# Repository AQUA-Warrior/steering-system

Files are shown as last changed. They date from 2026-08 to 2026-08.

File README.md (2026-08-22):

## Custom Steering + Throttle/Brake System & Devboard

> *If You Want Total Control, You Have To Make It Yourself*

### Project Overview:
A custom, embedded hardware project to make my very own sim racing steering wheel and pedal systems. The project is powered by the STM32F732RET6 chip, using hall effect sensors for measuring inputs of the steering, throttle, and braking.

### Purpose Of The Project:
I started making this project knowing basically nothing about communication protocols or chip architectures. Instead of buying adapters that are already made for you. I wanted to make the entire system myself to learn and expand my knowledge, and create my very own sim racing setup. By designing this myself, I learned the strengths and weaknesses of communication protocols and which ones were best for which purpose. I wired up all the unused GPIO pins on the chip to connectors so that I would not just be locked down to the steering project, but instead, I can use it as a general purpose devboard for any future embedded hardware project I want to do.

### The Repository Contains:
- KiCad schematics and PCB's for the devboard and AS5048A adapter board.
- STM32CubeMX pinouts for the devboard.
- This repository will in the future contain the firmware/software.

### Main Board Hardware:
- **Chip:** STM32F732RET6 (64-pin)
- **Power:** 5V VBUS from the USB-C, regulated to 3V3 using an AP2112k

### Main Board Design:
- 2 Layer PCB
- Minimum component size of 0603 used
- Two mounting holes (One on top right, One on bottom left)
- GND Zone on front copper
- 3V3 Zone on back copper

### AS5048A Adapter Board Design:
- 1 Layer PCB
- Minimum component size of 0603 used
- Two mounting holes (One on top right, One on bottom left)
- GND Zone on front copper

## Visuals
### Main Board Schematic:
main_schematic

### Main Board PCB:
main_PCB

### Main Board 3D View:
main_3D

### AS5048A Adapter Board Schematic:
AS5048A_schematic

### AS5048A Adapter Board PCB:
AS5048A_PCB

### AS5048A Adapter Board 3D View:
AS5048A_3D

## Bill Of Materials:

### Main Board:

| # | Reference | Qty | Value | Manufacturer | Manufacturer Part # | Footprint | Description | Price (1 Component) | Link |
|---:|---|---:|---|---|---|---|---|---:|---|
| 1 | F1 | 1 | Polyfuse | YAGEO | SMD0603B050TF | `Fuse:Fuse_0603_1608Metric_Pad1.05x0.95mm_HandSolder` | Resettable fuse, polymeric positive temperature coefficient | $0.36 | [DigiKey](https://www.digikey.ca/en/products/detail/yageo/SMD0603B050TF/15212923) |
| 2 | SW2 | 1 | SW_SPDT | Wurth Elektronik | 4.5E+11 | `450406020024:450406020024` | 9.0 × 3.5 mm, SPDT, ON-ON, Pitch 2.5 mm, Vertical type, SMT, T&R | $2.51 | [DigiKey](https://www.digikey.ca/en/products/detail/w%C3%BCrth-elektronik/450406020024/26249501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) |
| 3 | D1 | 1 | RED | Wurth Elektronik | 150060RS75000 | `LED_SMD:LED_0603_1608Metric_Pad1.05x0.95mm_HandSolder` | Light emitting diode | $0.15 | [DigiKey](https://www.digikey.ca/en/products/detail/w%C3%BCrth-elektronik/150060RS75000/4489901) |
| 4 | U2 | 1 | USBLC6-2SC6 | Shenzhen Slkormicro Semicon Co., Ltd. | USBLC6-2SC6 | `Package_TO_SOT_SMD:SOT-23-6` | Very low capacitance ESD protection diode, 2 data-line, SOT-23-6 | $0.18 | [DigiKey](https://www.digikey.ca/en/products/detail/shenzhen-slkormicro-semicon-co-ltd/USBLC6-2SC6/28143029) |
| 5 | U1 | 1 | STM32F732RET6 | STMicroelectronics | STM32F732RET6 | `Package_QFP:LQFP-64_10x10mm_P0.5mm` | STMicroelectronics Arm Cortex-M7 MCU, 512KB flash, 256KB RAM, 216 MHz, 1.7–3.6V, 50 GPIO, LQFP64 | $15.43 | [DigiKey](https://www.digikey.ca/en/products/detail/stmicroelectronics/STM32F732RET6/6621779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) |
| 6 | R4 | 1 | 100 | Panasonic Industry | ERJ-PA3F1000V | `Resistor_SMD:R_0603_1608Metric_Pad0.98x0.95mm_HandSolder` | Resistor | $0.24 | [DigiKey](https://www.digikey.ca/en/products/detail/panasonic-industry/ERJ-PA3F1000V/5035847) |
| 7 | R2, R3 | 2 | 5.1k | Panasonic Industry | ERJ-3GEYJ512V | `Resistor_SMD:R_0603_1608Metric_Pad0.98x0.95mm_HandSolder` | Resistor | $0.10 | [DigiKey](https://www.digikey.ca/en/products/detail/panasonic-industry/ERJ-3GEYJ512V/135918) |
| 8 | R1 | 1 | 10k | Panasonic Industry | ERJ-3EKF1002V | `Resistor_SMD:R_0603_1608Metric_Pad0.98x0.95mm_HandSolder` | Resistor | $0.10 | [DigiKey](https://www.digikey.ca/en/products/detail/panasonic-industry/ERJ-3EKF1002V/196066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) |
| 9 | FB1 | 1 | 120R | Murata Electronics | BLM18AG121SN1D | `Inductor_SMD:L_0603_1608Metric_Pad1.05x0.95mm_HandSolder` | Ferrite bead | $0.16 | [DigiKey](https://www.digikey.ca/en/products/detail/murata-electronics/BLM18AG121SN1D/584222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) |
| 10 | C16 | 1 | 2.2uF | Murata Electronics | GRT188R61H225KE13D | `Capacitor_SMD:C_0603_1608Metric_Pad1.08x0.95mm_HandSolder` | Unpolarized capacitor | $0.20 | [DigiKey](https://www.digikey.ca/en/products/detail/murata-electronics/GRT188R61H225KE13D/5416754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) |
| 11 | C11, C12 | 2 | 10pF | Murata Electronics | GCM1555C1H100JA16D | `Capacitor_SMD:C_0603_1608Metric_Pad1.08x0.95mm_HandSolder` | Unpolarized capacitor | $0.11 | [DigiKey](https://www.digikey.ca/en/products/detail/murata-electronics/GCM1555C1H100JA16D/4903546) |
| 12 | C8, C9, C14, C15 | 4 | 1uF | Murata Electronics | GRT188C8YA105KE13D | `Capacitor_SMD:C_0603_1608Metric_Pad1.08x0.95mm_HandSolder` | Unpolarized capacitor | $0.17 | [DigiKey](https://www.digikey.ca/en/products/detail/murata-electronics/GRT188C8YA105KE13D/5416719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) |
| 13 | C7 | 1 | 10nF | Murata Electronics | GCM188R72A103KA37D | `Capacitor_SMD:C_0603_1608Metric_Pad1.08x0.95mm_HandSolder` | Unpolarized capacitor | $0.15 | [DigiKey](https://www.digikey.ca/en/products/detail/murata-electronics/GCM188R72A103KA37D/1641655) |
| 14 | C6, C17 | 2 | 10uF | Murata Electronics | GCJ21BR71A106KE01L | `Capacitor_SMD:C_0805_2012Metric_Pad1.18x1.45mm_HandSolder` | Unpolarized capacitor | $0.74 | [DigiKey](https://www.digikey.ca/en/products/detail/murata-electronics/GCJ21BR71A106KE01L/4903511) |
| 15 | C1, C2, C3, C4, C5, C10 | 6 | 100nF | Murata Electronics | GCM188L81H104KA57D | `Capacitor_SMD:C_0603_1608Metric_Pad1.08x0.95mm_HandSolder` | Unpolarized capacitor | $0.14 | [DigiKey](https://www.digikey.ca/en/products/detail/murata-electronics/GCM188L81H104KA57D/2591908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) |
| 16 | D2 | 1 | D_TVS | KYOCERA AVX | GG060305100N2P | `Diode_SMD:D_0603_1608Metric_Pad1.05x0.95mm_HandSolder` | Bidirectional transient-voltage-suppression diode | $0.45 | [DigiKey](https://www.digikey.ca/en/products/detail/kyocera-avx/GG060305100N2P/14552130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) |
| 17 | Y1 | 1 | 16MHz | Jauch Quartz | Q 16,0-JXS32-8-10/10-WA-LF | `Crystal:Crystal_SMD_3225-4Pin_3.2x2.5mm_HandSoldering` | Four pin crystal, GND on pins 2 and 4 | $0.61 | [DigiKey](https://www.digikey.ca/en/products/detail/jauch-quartz/Q-16-0-JXS32-8-10-10-WA-LF/8108046) |
| 18 | J1 | 1 | USB_C_Receptacle_USB2.0_14P | GCT | USB4085-GF-A | `Connector_USB:USB_C_Receptacle_GCT_USB4085` | USB 2.0-only 14P Type-C Receptacle connector | $0.91 | [DigiKey](https://www.digikey.ca/en/products/detail/gct/USB4085-GF-A/9859662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) |
| 19 | U3 | 1 | AP2112K-3.3 | Diodes Incorporated | AP2112K-3.3TRG1 | `Package_TO_SOT_SMD:SOT-23-5` | 600mA low dropout linear regulator, with enable pin, 3.8–6V input voltage range, 3.3V fixed positive output, SOT-23-5 | $0.28 | [DigiKey](https://www.digikey.ca/en/products/detail/diodes-incorporated/AP2112K-3-3TRG1/4470746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) |
| 20 | SW1 | 1 | SW_Push | Alps Alpine | SKSGACE010 | `ul_SKSGACE010:SKSGACE010_ALPS` | Push button switch, generic, two pins | $0.45 | [DigiKey](https://www.digikey.ca/en/products/detail/alps-alpine/SKSGACE010/19529157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) |
| 21 | J8 | 1 | Conn_01x15_Socket | — | — | `Connector_PinHeader_2.54mm:PinHeader_1x15_P2.54mm_Vertical` | Generic connector, single row, 01x15, script generated | — | — |
| 22 | J7 | 1 | Conn_01x21_Socket | — | — | `Connector_PinHeader_2.54mm:PinHeader_1x21_P2.54mm_Vertical` | Generic connector, single row, 01x21, script generated | — | — |
| 23 | J6 | 1 | Conn_01x02_Socket USART2 | — | — | `Connector_PinHeader_2.54mm:PinHeader_1x02_P2.54mm_Vertical` | Generic connector, single row, 01x02, script generated | — | — |
| 24 | J4, J5 | 2 | Conn_01x03_Socket A1324LLHLT-T | — | — | `Connector_PinHeader_2.54mm:PinHeader_1x03_P2.54mm_Vertical` | Generic connector, single row, 01x03, script generated | — | — |
| 25 | J3 | 1 | Conn_01x06_Socket | — | — | `Connector_PinHeader_2.54mm:PinHeader_1x06_P2.54mm_Vertical` | Generic connector, single row, 01x06, script generated | — | — |
| 26 | J2 | 1 | Conn_01x04_Pin | — | — | `Connector_PinHeader_2.54mm:PinHeader_1x04_P2.54mm_Vertical` | Generic connector, single row, 01x04, script generated | — | — |

### AS5048 Adapter Board:

| # | Reference | Qty | Value | Manufacturer | Manufacturer Part # | Footprint | Description | Price (1 Component) | Link |
|---:|---|---:|---|---|---|---|---|---:|---|
| 1 | C1 | 1 | 100nF | Murata Electronics | GCM188L81H104KA57D | `Capacitor_SMD:C_0603_1608Metric_Pad1.08x0.95mm_HandSolder` | Unpolarized capacitor | $0.14 | [DigiKey](https://www.digikey.ca/en/products/detail/murata-electronics/GCM188L81H104KA57D/2591908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) |
| 2 | C2 | 1 | 10uF | Murata Electronics | GCJ21BR71A106KE01L | `Capacitor_SMD:C_0805_2012Metric_Pad1.18x1.45mm_HandSolder` | Unpolarized capacitor | $0.50 | [DigiKey](https://www.digikey.ca/en/products/detail/murata-electronics/GCJ21BR71A106KE01L/4903511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) |
| 3 | J1 | 1 | Conn_01x07_Socket | — | — | `Connector_PinHeader_2.54mm:PinHeader_1x07_P2.54mm_Vertical` | Generic connector, single row, 01x07, script generated | — | — |
| 4 | U1 | 1 | AS5048A | ams OSRAM AG | AS5048A-HTSP-500 | `Package_SO:TSSOP-14_4.4x5mm_P0.65mm` | Magnetic position sensor, 14-bit, PWM output, SPI Interface, TSSOP-14 | $8.80 | [DigiKey](https://www.digikey.ca/en/products/detail/ams-osram-ag/AS5048A-HTSP-500/3188615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) |

### Linear Sensor:

| # | Reference | Qty | Value | Manufacturer | Manufacturer Part # | Footprint | Description | Price (1 Component) | Link |
|---:|---|---:|---|---|---|---|---|---:|---|
| 1 | — | 1 | — | Texas Instruments | DRV5055A1QLPG | — | SEN HALL EFFECT ANLG VOLT TO92-3 | $0.77 | [Digikey](https://www.digikey.ca/en/products/detail/texas-instruments/DRV5055A1QLPG) |

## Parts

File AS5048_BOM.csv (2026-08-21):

# | Reference | Qty | Value | MANUFACTURER | Manufacturer Part # | Footprint | Description | Price (1 Component) | Link
1 | C1 | 1 | 100nF | Murata Electronics | GCM188L81H104KA57D | Capacitor_SMD:C_0603_1608Metric_Pad1.08x0.95mm_HandSolder | Unpolarized capacitor | $0.14 | https://www.digikey.com/en/products/detail/murata-electronics/GCM188L81H104KA57D/2591908
2 | C2 | 1 | 10uF | Murata Electronics | GCJ21BR71A106KE01L | Capacitor_SMD:C_0805_2012Metric_Pad1.18x1.45mm_HandSolder | Unpolarized capacitor | $0.5 | https://www.digikey.com/en/products/detail/murata-electronics/GCJ21BR71A106KE01L/4903511
3 | J1 | 1 | Conn_01x07_Socket |  |  | Connector_PinHeader_2.54mm:PinHeader_1x07_P2.54mm_Vertical | Generic connector, single row, 01x07, script generated
4 | U1 | 1 | AS5048A | ams OSRAM AG | AS5048A-HTSP-500 | Package_SO:TSSOP-14_4.4x5mm_P0.65mm | Magnetic position sensor, 14-bit, PWM output, SPI Interface, TSSOP-14 | $8.8 | https://www.digikey.com/en/products/detail/ams-osram-ag/AS5048A-HTSP-500/3188615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

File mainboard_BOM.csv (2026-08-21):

# | Reference | Qty | Value | MANUFACTURER | Manufacturer Part # | Footprint | Description | Price (1 Component) | Link
1 | F1 | 1 | Polyfuse | YAGEO | SMD0603B050TF | Fuse:Fuse_0603_1608Metric_Pad1.05x0.95mm_HandSolder | Resettable fuse, polymeric positive temperature coefficient | $0.36 | https://www.digikey.ca/en/products/detail/yageo/SMD0603B050TF/15212923
2 | SW2 | 1 | SW_SPDT | Wurth Elektronik | 450406020024 | 450406020024:450406020024 | 9.0*3.5 mm, SPDT, ON-ON, Pitch 2.5mm, Vertical type, SMT, T&R | $2.51 | https://www.digikey.com/en/products/detail/w%C3%BCrth-elektronik/450406020024/26249501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
3 | D1 | 1 | RED | Wurth Elektronik | 150060RS75000 | LED_SMD:LED_0603_1608Metric_Pad1.05x0.95mm_HandSolder | Light emitting diode | $0.15 | https://www.digikey.com/en/products/detail/w%C3%BCrth-elektronik/150060RS75000/4489901
4 | U1 | 1 | STM32F732RET6 | STMicroelectronics | STM32F732RET6 | Package_QFP:LQFP-64_10x10mm_P0.5mm | STMicroelectronics Arm Cortex-M7 MCU, 512KB flash, 256KB RAM, 216 MHz, 1.7-3.6V, 50 GPIO, LQFP64 | $15.43 | https://www.digikey.com/en/products/detail/stmicroelectronics/STM32F732RET6/6621779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
5 | U2 | 1 | USBLC6-2SC6 | Shenzhen Slkormicro Semicon Co., Ltd. | USBLC6-2SC6 | Package_TO_SOT_SMD:SOT-23-6 | Very low capacitance ESD protection diode, 2 data-line, SOT-23-6 | $0.18 | https://www.digikey.com/en/products/detail/shenzhen-slkormicro-semicon-co-ltd/USBLC6-2SC6/28143029
6 | R4 | 1 | 100 | Panasonic Industry | ERJ-PA3F1000V | Resistor_SMD:R_0603_1608Metric_Pad0.98x0.95mm_HandSolder | Resistor | $0.24 | https://www.digikey.ca/en/products/detail/panasonic-industry/ERJ-PA3F1000V/5035847
7 | R2,R3 | 2 | 5.1k | Panasonic Industry | ERJ-3EKF5101V | Resistor_SMD:R_0603_1608Metric_Pad0.98x0.95mm_HandSolder | Resistor | $0.15 | https://www.digikey.com/en/products/detail/panasonic-industry/ERJ-PA3F1000V/5035847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
8 | R1 | 1 | 10k | Panasonic Industry | ERJ-3EKF1002V | Resistor_SMD:R_0603_1608Metric_Pad0.98x0.95mm_HandSolder | Resistor | $0.1 | https://www.digikey.com/en/products/detail/panasonic-industry/ERJ-3EKF1002V/196066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
9 | FB1 | 1 | 120R | Murata Electronics | BLM18AG121SN1D | Inductor_SMD:L_0603_1608Metric_Pad1.05x0.95mm_HandSolder | Ferrite bead | $0.16 | https://www.digikey.ca/en/products/detail/murata-electronics/BLM18AG121SN1D/584222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
10 | C16 | 1 | 2.2uF | Murata Electronics | GRT188R61H225KE13D | Capacitor_SMD:C_0603_1608Metric_Pad1.08x0.95mm_HandSolder | Unpolarized capacitor | $0.2 | https://www.digikey.com/en/products/detail/murata-electronics/GRT188R61H225KE13D/5416754
11 | C11,C12 | 2 | 10pF | Murata Electronics | GCM1555C1H100JA16D | Capacitor_SMD:C_0603_1608Metric_Pad1.08x0.95mm_HandSolder | Unpolarized capacitor | $0.11 | https://www.digikey.com/en/products/detail/murata-electronics/GCM1555C1H100JA16D/4903546
12 | C8,C9,C14,C15 | 4 | 1uF | Murata Electronics | GRT188C8YA105KE13D | Capacitor_SMD:C_0603_1608Metric_Pad1.08x0.95mm_HandSolder | Unpolarized capacitor | $0.17 | https://www.digikey.com/en/products/detail/murata-electronics/GRT188C8YA105KE13D/5416719
13 | C7 | 1 | 10nF | Murata Electronics | GCM188R72A103KA37D | Capacitor_SMD:C_0603_1608Metric_Pad1.08x0.95mm_HandSolder | Unpolarized capacitor | $0.15 | https://www.digikey.ca/en/products/detail/murata-electronics/GCM188R72A103KA37D/1641655
14 | C6,C17 | 2 | 10uF | Murata Electronics | GCJ21BR71A106KE01L | Capacitor_SMD:C_0805_2012Metric_Pad1.18x1.45mm_HandSolder | Unpolarized capacitor | $0.74 | https://www.digikey.ca/en/products/detail/murata-electronics/GCJ21BR71A106KE01L/4903511
15 | C1,C2,C3,C4,C5,C10 | 6 | 100nF | Murata Electronics | GCM188L81H104KA57D | Capacitor_SMD:C_0603_1608Metric_Pad1.08x0.95mm_HandSolder | Unpolarized capacitor | $0.14 | https://www.digikey.com/en/products/detail/murata-electronics/GCM188L81H104KA57D/2591908
16 | D2 | 1 | D_TVS | KYOCERA AVX | GG060305100N2P | Diode_SMD:D_0603_1608Metric_Pad1.05x0.95mm_HandSolder | Bidirectional transient-voltage-suppression diode | $0.45 | https://www.digikey.ca/en/products/detail/kyocera-avx/GG060305100N2P/14552130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
17 | Y1 | 1 | 16MHz | Jauch Quartz | Q 16,0-JXS32-8-10/10-WA-LF | Crystal:Crystal_SMD_3225-4Pin_3.2x2.5mm_HandSoldering | Four pin crystal, GND on pins 2 and 4 | $0.61 | https://www.digikey.com/en/products/detail/jauch-quartz/Q-16-0-JXS32-8-10-10-WA-LF/8108046
18 | J1 | 1 | USB_C_Receptacle_USB2.0_14P | GCT | USB4085-GF-A | Connector_USB:USB_C_Receptacle_GCT_USB4085 | USB 2.0-only 14P Type-C Receptacle connector | $0.91 | https://www.digikey.com/en/products/detail/gct/USB4085-GF-A/9859662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
19 | U3 | 1 | AP2112K-3.3 | Diodes Incorporated | AP2112K-3.3TRG1 | Package_TO_SOT_SMD:SOT-23-5 | 600mA low dropout linear regulator, with enable pin, 3.8V-6V input voltage range, 3.3V fixed positive output, SOT-23-5 | $0.28 | https://www.digikey.com/en/products/detail/diodes-incorporated/AP2112K-3-3TRG1/4470746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
20 | SW1 | 1 | SW_Push | Alps Alpine | SKSGACE010 | ul_SKSGACE010:SKSGACE010_ALPS | Push button switch, generic, two pins | $0.45 | https://www.digikey.com/en/products/detail/alps-alpine/SKSGACE010/19529157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
21 | J8 | 1 | Conn_01x15_Socket |  |  | Connector_PinHeader_2.54mm:PinHeader_1x15_P2.54mm_Vertical | Generic connector, single row, 01x15, script generated
22 | J7 | 1 | Conn_01x21_Socket |  |  | Connector_PinHeader_2.54mm:PinHeader_1x21_P2.54mm_Vertical | Generic connector, single row, 01x21, script generated
23 | J6 | 1 | Conn_01x02_Socket USART2 |  |  | Connector_PinHeader_2.54mm:PinHeader_1x02_P2.54mm_Vertical | Generic connector, single row, 01x02, script generated
24 | J4,J5 | 2 | Conn_01x03_Socket A1324LLHLT-T |  |  | Connector_PinHeader_2.54mm:PinHeader_1x03_P2.54mm_Vertical | Generic connector, single row, 01x03, script generated
25 | J3 | 1 | Conn_01x06_Socket |  |  | Connector_PinHeader_2.54mm:PinHeader_1x06_P2.54mm_Vertical | Generic connector, single row, 01x06, script generated
26 | J2 | 1 | Conn_01x04_Pin |  |  | Connector_PinHeader_2.54mm:PinHeader_1x04_P2.54mm_Vertical | Generic connector, single row, 01x04, script generated

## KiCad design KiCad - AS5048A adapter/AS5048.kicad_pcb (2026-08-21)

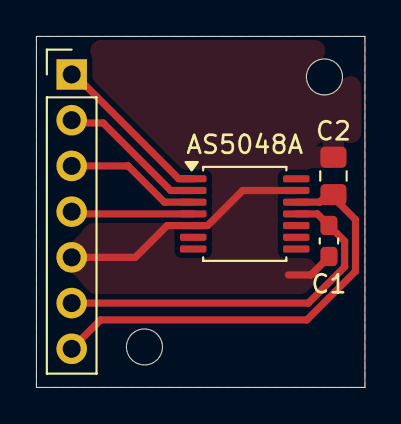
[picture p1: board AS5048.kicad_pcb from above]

Board: 2 copper layers, 18.2 x 19.5 mm, 4 parts (0 on the bottom side), 7 nets.

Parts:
AS5048A: AS5048A; TSSOP-14_4.4x5mm_P0.65mm
C1: 100nF; C_0603_1608Metric_Pad1.08x0.95mm_HandSolder
C2: 10uF; C_0805_2012Metric_Pad1.18x1.45mm_HandSolder
J1: Conn_01x07_Socket; PinHeader_1x07_P2.54mm_Vertical

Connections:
+3V3: AS5048A.12 (VDD3V), C2.1, J1.7
+5V: AS5048A.11 (VDD5V), C1.2, J1.6
/CLK: AS5048A.2 (CLK), J1.2
/CS: AS5048A.1 (~CSn), J1.1
/MISO: AS5048A.3 (MISO), J1.3
/MOSI: AS5048A.4 (MOSI), J1.4
GND: AS5048A.5 (TEST), AS5048A.13 (GND), C1.1, C2.2, J1.5

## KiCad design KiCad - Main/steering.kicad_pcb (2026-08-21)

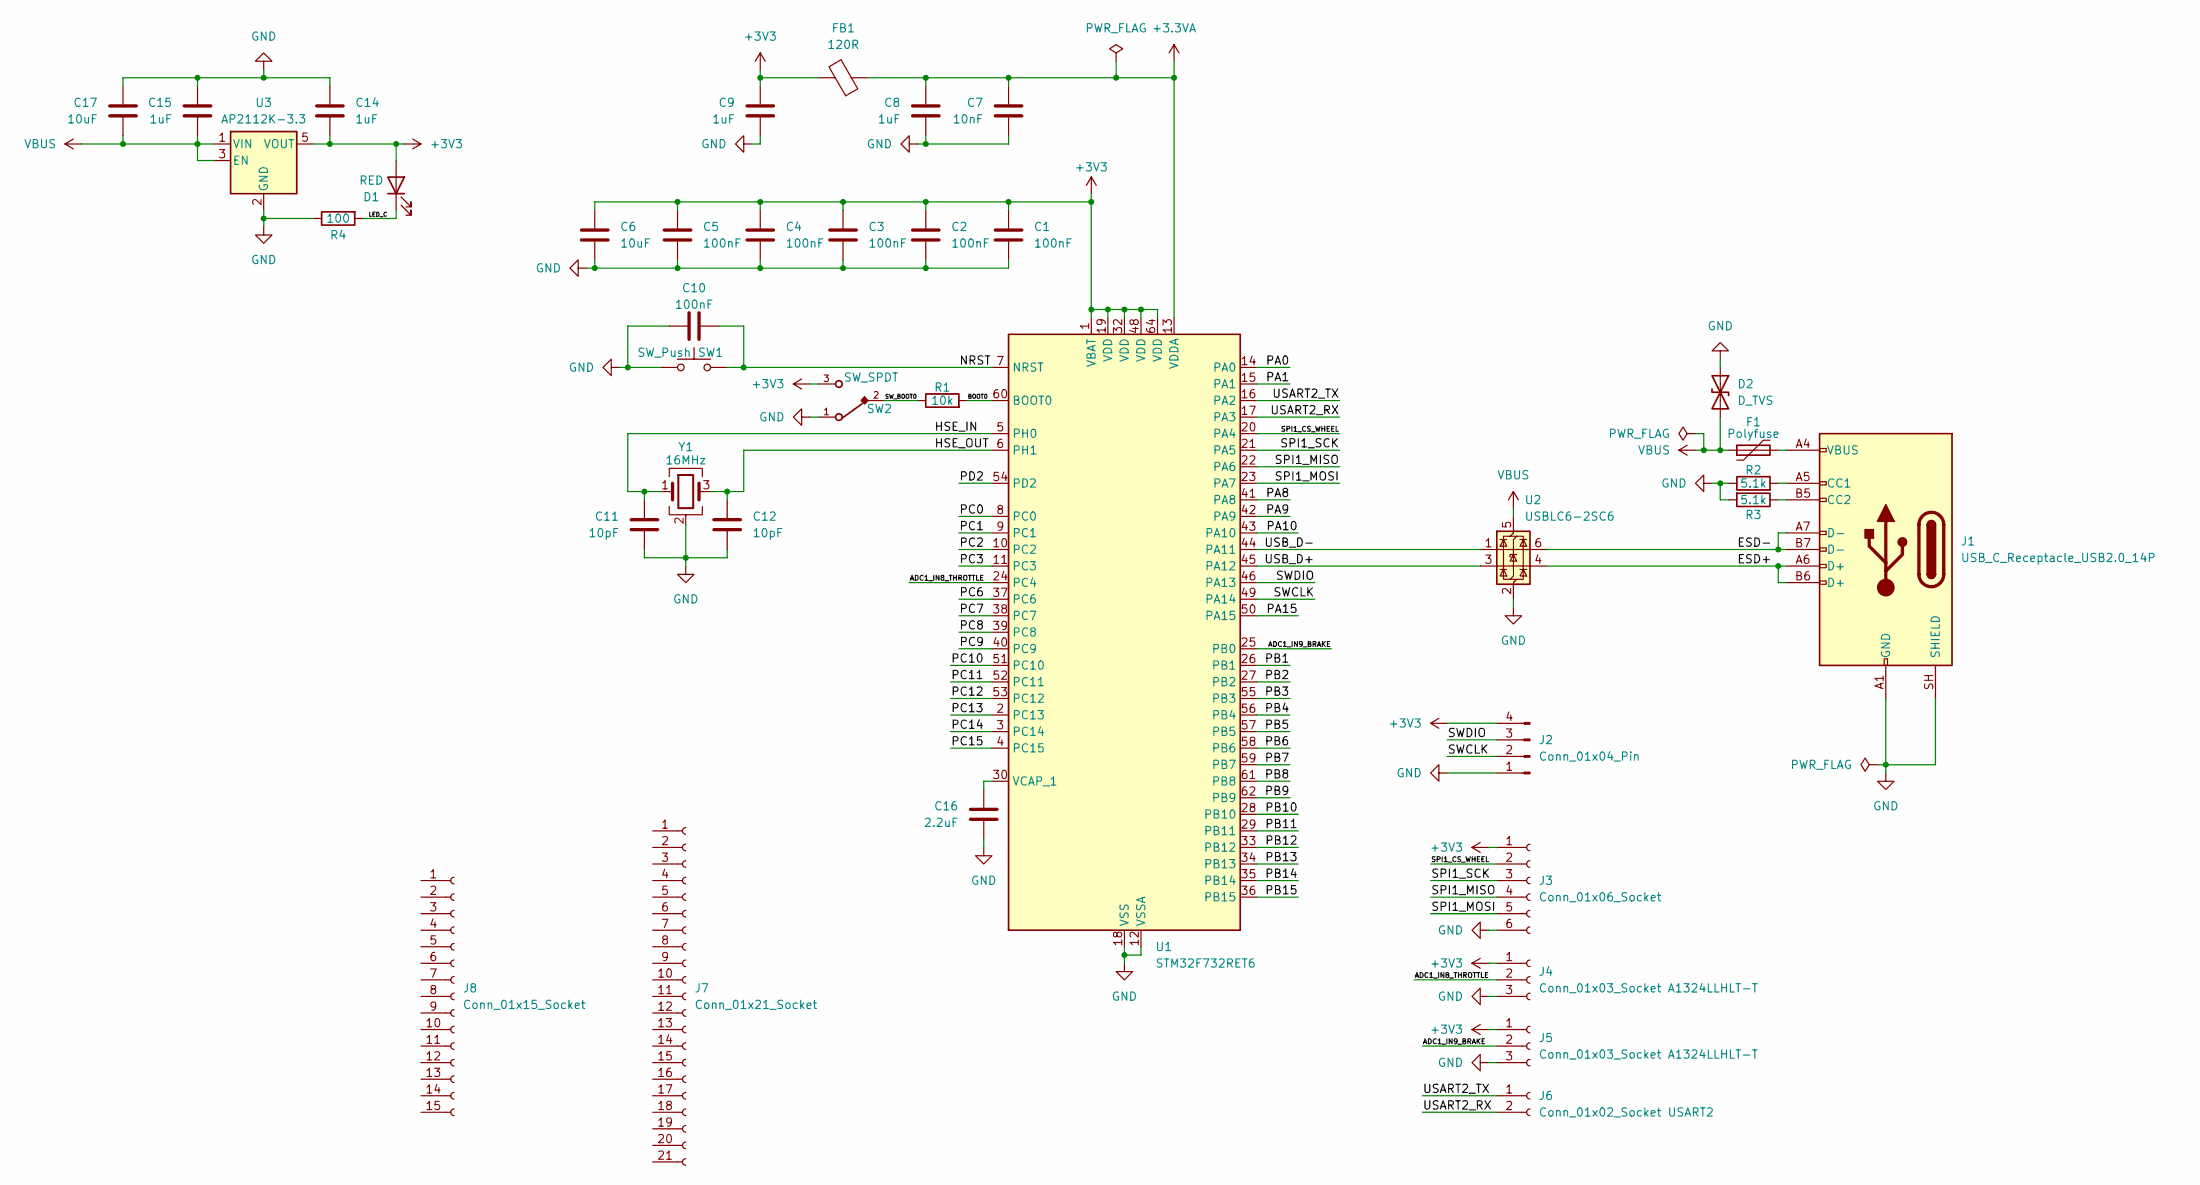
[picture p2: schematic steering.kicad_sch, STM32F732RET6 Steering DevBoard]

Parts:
C1, C2, C3, C4, C5, C10: 100nF; C_0603_1608Metric_Pad1.08x0.95mm_HandSolder
C6, C17: 10uF; C_0805_2012Metric_Pad1.18x1.45mm_HandSolder
C7: 10nF; C_0603_1608Metric_Pad1.08x0.95mm_HandSolder
C8, C9, C14, C15: 1uF; C_0603_1608Metric_Pad1.08x0.95mm_HandSolder
C11, C12: 10pF; C_0603_1608Metric_Pad1.08x0.95mm_HandSolder
C16: 2.2uF; C_0603_1608Metric_Pad1.08x0.95mm_HandSolder
D1: RED; LED_0603_1608Metric_Pad1.05x0.95mm_HandSolder
D2: D_TVS; D_0603_1608Metric_Pad1.05x0.95mm_HandSolder
F1: Polyfuse; Fuse_0603_1608Metric_Pad1.05x0.95mm_HandSolder
FB1: 120R; L_0603_1608Metric_Pad1.05x0.95mm_HandSolder
J1: USB_C_Receptacle_USB2.0_14P; USB_C_Receptacle_GCT_USB4085
J2: Conn_01x04_Pin; PinHeader_1x04_P2.54mm_Vertical
J3: Conn_01x06_Socket; PinHeader_1x06_P2.54mm_Vertical
J4, J5: Conn_01x03_Socket A1324LLHLT-T; PinHeader_1x03_P2.54mm_Vertical
J6: Conn_01x02_Socket USART2; PinHeader_1x02_P2.54mm_Vertical
J7: Conn_01x21_Socket; PinHeader_1x21_P2.54mm_Vertical
J8: Conn_01x15_Socket; PinHeader_1x15_P2.54mm_Vertical
R1: 10k; R_0603_1608Metric_Pad0.98x0.95mm_HandSolder
R2, R3: 5.1k; R_0603_1608Metric_Pad0.98x0.95mm_HandSolder
R4: 100; R_0603_1608Metric_Pad0.98x0.95mm_HandSolder
SW1: SW_Push; SKSGACE010_ALPS
SW2: SW_SPDT; 450406020024; DigiKey_Part_Number 732-450406020024CT-ND
U1: STM32F732RET6; LQFP-64_10x10mm_P0.5mm
U2: USBLC6-2SC6; SOT-23-6
U3: AP2112K-3.3; SOT-23-5
Y1: 16MHz; Crystal_SMD_3225-4Pin_3.2x2.5mm_HandSoldering

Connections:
+3.3VA: C7.1, C8.1, FB1.1, U1.13 (VDDA)
+3V3: C1.1, C2.1, C3.1, C4.1, C5.1, C6.1, C9.1, C14.2, D1.2 (A), FB1.2, J2.4, J3.1, J4.1, J5.1, SW2.3, U1.1 (VBAT), U1.19 (VDD), U1.32 (VDD), U1.48 (VDD), U1.64 (VDD), U3.5 (VOUT)
/ADC1_IN8_THROTTLE: J4.2, U1.24 (PC4)
/ADC1_IN9_BRAKE: J5.2, U1.25 (PB0)
/BOOT0: R1.2, U1.60 (BOOT0)
/ESD+: J1.A6 (D+), J1.B6 (D+), U2.4 (I/O2)
/ESD-: J1.A7 (D-), J1.B7 (D-), U2.6 (I/O1)
/HSE_IN: C11.2, U1.5 (PH0), Y1.1
/HSE_OUT: C12.1, U1.6 (PH1), Y1.3
/LED_C: D1.1 (K), R4.2
/NRST: C10.1, SW1.2, U1.7 (NRST)
/PA0: U1.14 (PA0)
/PA1: U1.15 (PA1)
/PA8: U1.41 (PA8)
/PA9: U1.42 (PA9)
/PA10: U1.43 (PA10)
/PA15: U1.50 (PA15)
/PB1: U1.26 (PB1)
/PB2: U1.27 (PB2)
/PB3: U1.55 (PB3)
/PB4: U1.56 (PB4)
/PB5: U1.57 (PB5)
/PB6: U1.58 (PB6)
/PB7: U1.59 (PB7)
/PB8: U1.61 (PB8)
/PB9: U1.62 (PB9)
/PB10: U1.28 (PB10)
/PB11: U1.29 (PB11)
/PB12: U1.33 (PB12)
/PB13: U1.34 (PB13)
/PB14: U1.35 (PB14)
/PB15: U1.36 (PB15)
/PC0: U1.8 (PC0)
/PC1: U1.9 (PC1)
/PC2: U1.10 (PC2)
/PC3: U1.11 (PC3)
/PC6: U1.37 (PC6)
/PC7: U1.38 (PC7)
/PC8: U1.39 (PC8)
/PC9: U1.40 (PC9)
/PC10: U1.51 (PC10)
/PC11: U1.52 (PC11)
/PC12: U1.53 (PC12)
/PC13: U1.2 (PC13)
/PC14: U1.3 (PC14)
/PC15: U1.4 (PC15)
/PD2: U1.54 (PD2)
/SPI1_CS_WHEEL: J3.2, U1.20 (PA4)
/SPI1_MISO: J3.4, U1.22 (PA6)
/SPI1_MOSI: J3.5, U1.23 (PA7)
/SPI1_SCK: J3.3, U1.21 (PA5)
/SWCLK: J2.2, U1.49 (PA14)
/SWDIO: J2.3, U1.46 (PA13)
/SW_BOOT0: R1.1, SW2.2
/USART2_RX: J6.2, U1.17 (PA3)
/USART2_TX: J6.1, U1.16 (PA2)
/USB_D+: U1.45 (PA12), U2.3 (I/O2)
/USB_D-: U1.44 (PA11), U2.1 (I/O1)
GND: C1.2, C2.2, C3.2, C4.2, C5.2, C6.2, C7.2, C8.2, C9.2, C10.2, C11.1, C12.2, C14.1, C15.2, C16.2, C17.2, D2.1 (A1), J1.A1 (GND), J1.A12 (GND), J1.B1 (GND), J1.B12 (GND), J1.SH (SHIELD), J2.1, J3.6, J4.3, J5.3, R2.1, R3.2, R4.1, SW1.1, SW2.1, U1.12 (VSSA), U1.18 (VSS), U1.31 (VSS), U1.47 (VSS), U1.63 (VSS), U2.2 (GND), U3.2 (GND), Y1.2 (G), Y1.4 (G)
unnamed: F1.2, J1.A4 (VBUS), J1.A9 (VBUS), J1.B4 (VBUS), J1.B9 (VBUS)
unnamed: J1.A5 (CC1), R2.2
unnamed: J1.B5 (CC2), R3.1
unnamed: C16.1, U1.30 (VCAP_1)
VBUS: C15.1, C17.1, D2.2 (A2), F1.1, U2.5 (VBUS), U3.1 (VIN), U3.3 (EN)

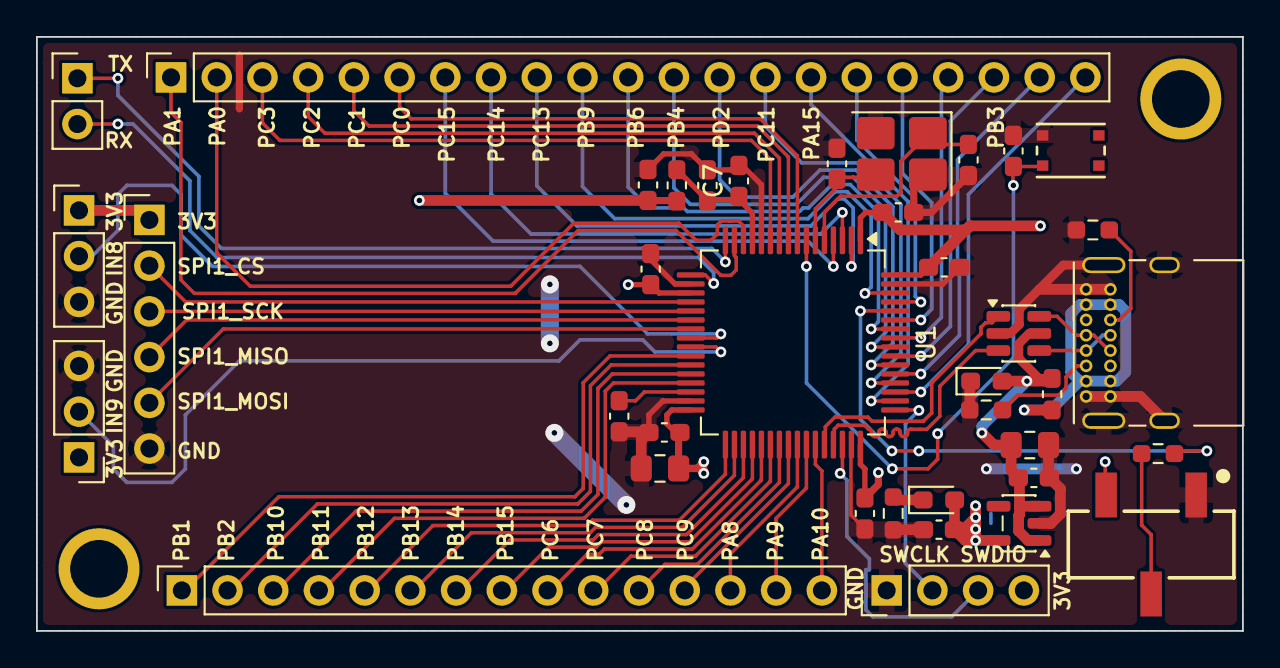
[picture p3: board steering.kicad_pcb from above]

Board: 2 copper layers, 67.0 x 33.0 mm, 36 parts (0 on the bottom side), 28 nets.

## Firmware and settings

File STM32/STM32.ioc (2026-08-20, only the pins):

Mcu.UserName=STM32F732RETx
PA11.Signal=USB_OTG_FS_DM
PA12.Signal=USB_OTG_FS_DP
PA13.Signal=SYS_JTMS-SWDIO
PA14.Signal=SYS_JTCK-SWCLK
PA2.Signal=USART2_TX
PA3.Signal=USART2_RX
PA4.Signal=GPIO_Output
PA5.Signal=SPI1_SCK
PA6.Signal=SPI1_MISO
PA7.Signal=SPI1_MOSI
PA9.Signal=USB_OTG_FS_VBUS
PB0.Signal=ADCx_IN8
PC4.Signal=ADCx_IN14
PH0-OSC_IN.Signal=RCC_OSC_IN
PH1-OSC_OUT.Signal=RCC_OSC_OUT

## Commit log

2026-08-21 BOM, pcbway stuff, and final check over
    [AS5048-B_Cu.gbr, AS5048-B_Mask.gbr, AS5048-B_Paste.gbr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]
2026-08-22 added linear sensor to BOM
    [steering.kicad_sch]
2026-10-23 replaced panasonic resistors with YAGEO
2026-10-23 added magnets and connectors in BOM
2026-10-26 updated capacitors
2026-11-11 changed 100 ohm and 10pf to 0402 sizes | added silkscreen text for components | changed mounting holes in adapter board | final check over everything
